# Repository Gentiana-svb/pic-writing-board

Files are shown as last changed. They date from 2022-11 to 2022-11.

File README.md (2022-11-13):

# pic-writing-board

PIC writing board for DIP package with auto guess pin count.

## Core Components

| | |
| --- | --- |
| Analog MUX | TMUX1309BQBR |
| MCU | PIC18F27Q10T-I/ML |
| Comparator | LM2901Q4T |
| SSR | TLP172AM |
| LDO | NJM2845 |
| Power SW | TCP8407 |

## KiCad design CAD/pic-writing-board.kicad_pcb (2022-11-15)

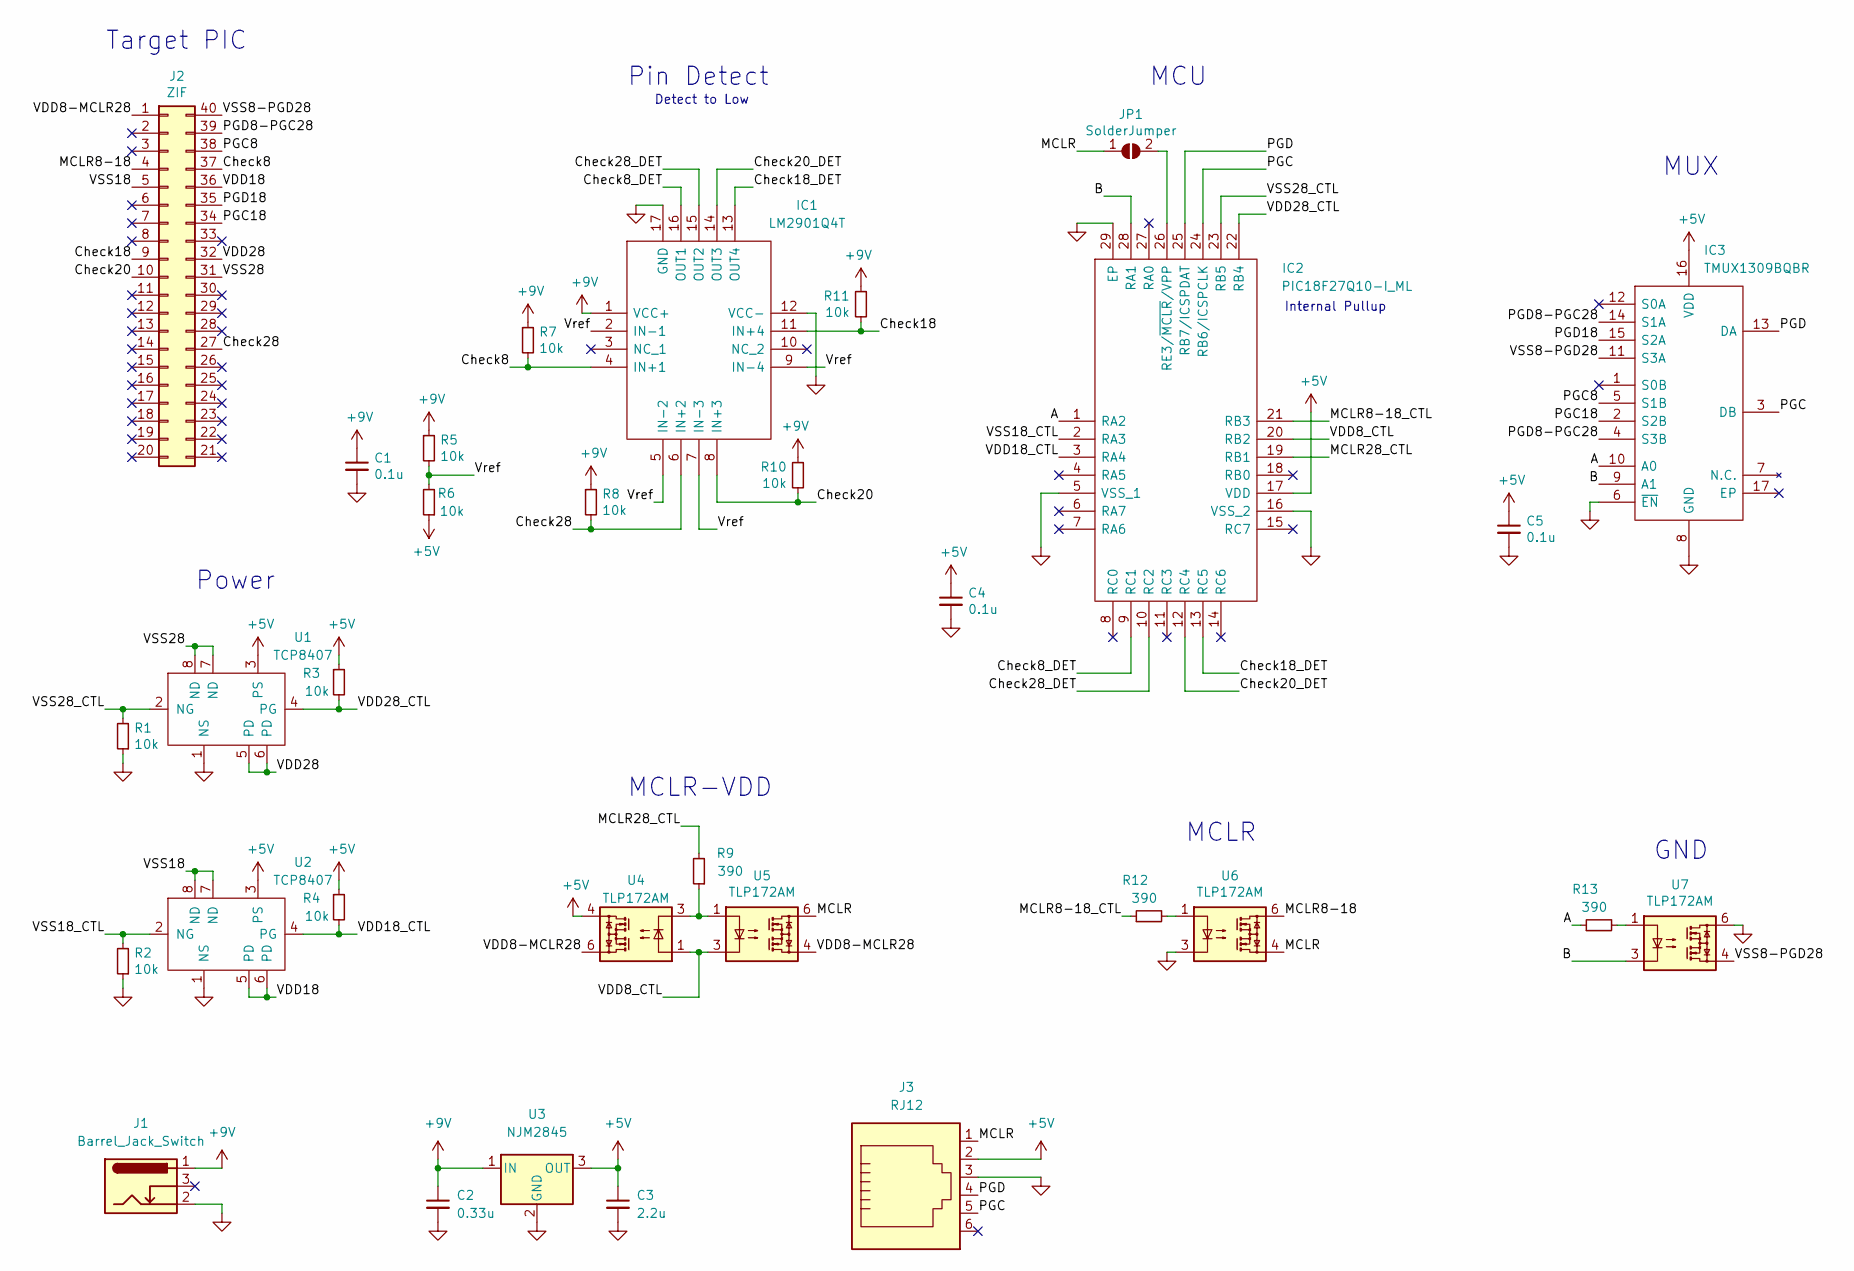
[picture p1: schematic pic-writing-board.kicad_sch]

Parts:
C1, C4, C5: 0.1u; C_0603_1608Metric
C2: 0.33u; C_0603_1608Metric
C3: 2.2u; C_0603_1608Metric
IC1: LM2901Q4T; QFN50P300X300X100-17N; Mouser Part Number 511-LM2901Q4T
IC2: PIC18F27Q10-I_ML; QFN65P600X600X100-29N-D; Mouser Part Number 579-PIC18F27Q10-I/ML
IC3: TMUX1309BQBR; Mouser Part Number 595-TMUX1309BQBR
J1: Barrel_Jack_Switch; BarrelJack_Wuerth_6941xx301002
J2: ZIF
J3: RJ12; 6P6C
JP1: SolderJumper; SolderJumper-2_P1.3mm_Open_RoundedPad1.0x1.5mm
R1, R2, R3, R4, R5, R6, R7, R8, R10, R11: 10k; R_0603_1608Metric
R9, R12, R13: 390; R_0603_1608Metric
U1, U2: TCP8407; SOP-8_3.9x4.9mm_P1.27mm
U3: NJM2845; TO-252-2
U4, U5, U6, U7: TLP172AM; SOIC-4_4.55x3.7mm_P2.54mm

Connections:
+5V: C3.1, C4.1, C5.1, IC2.17 (VDD), IC3.16 (VDD), J3.2, R3.1, R4.1, R6.1, U1.3 (PS), U2.3 (PS), U3.3 (OUT), U4.4
+9V: C1.1, C2.1, IC1.1 (VCC+), J1.1, R5.1, R7.1, R8.1, R10.1, R11.1, U3.1 (IN)
/A: IC2.1 (RA2), IC3.10 (A0), R13.1
/B: IC2.28 (RA1), IC3.9 (A1), U7.3
/Check8: IC1.4 (IN+1), J2.37, R7.2
/Check8_DET: IC1.16 (OUT1), IC2.9 (RC1)
/Check18: IC1.11 (IN+4), J2.9, R11.2
/Check18_DET: IC1.13 (OUT4), IC2.13 (RC5)
/Check20: IC1.8 (IN+3), J2.10, R10.2
/Check20_DET: IC1.14 (OUT3), IC2.12 (RC4)
/Check28: IC1.6 (IN+2), J2.27, R8.2
/Check28_DET: IC1.15 (OUT2), IC2.10 (RC2)
/MCLR: J3.1, JP1.1 (A), U5.6, U6.4
/MCLR8-18: J2.4, U6.6
/MCLR8-18_CTL: IC2.21 (RB3), R12.1
/MCLR28_CTL: IC2.19 (RB1), R9.2
/PGC: IC2.24 (RB6/ICSPCLK), IC3.3 (DB), J3.5
/PGC8: IC3.5 (S1B), J2.38
/PGC18: IC3.2 (S2B), J2.34
/PGD: IC2.25 (RB7/ICSPDAT), IC3.13 (DA), J3.4
/PGD8-PGC28: IC3.4 (S3B), IC3.14 (S1A), J2.39
/PGD18: IC3.15 (S2A), J2.35
/VDD8-MCLR28: J2.1, U4.6, U5.4
/VDD8_CTL: IC2.20 (RB2), U4.1, U5.3
/VDD18: J2.36, U2.5 (PD), U2.6 (PD)
/VDD18_CTL: IC2.3 (RA4), R4.2, U2.4 (PG)
/VDD28: J2.32, U1.5 (PD), U1.6 (PD)
/VDD28_CTL: IC2.22 (RB4), R3.2, U1.4 (PG)
/VSS8-PGD28: IC3.11 (S3A), J2.40, U7.4
/VSS18: J2.5, U2.7 (ND), U2.8 (ND)
/VSS18_CTL: IC2.2 (RA3), R2.2, U2.2 (NG)
/VSS28: J2.31, U1.7 (ND), U1.8 (ND)
/VSS28_CTL: IC2.23 (RB5), R1.2, U1.2 (NG)
/Vref: IC1.2 (IN-1), IC1.5 (IN-2), IC1.7 (IN-3), IC1.9 (IN-4), R5.2, R6.2
GND: C1.2, C2.2, C3.2, C4.2, C5.2, IC1.12 (VCC-), IC1.17 (GND), IC2.5 (VSS_1), IC2.16 (VSS_2), IC2.29 (EP), IC3.6 (~EN), IC3.8 (GND), J1.2, J3.3, R1.1, R2.1, U1.1 (NS), U2.1 (NS), U3.2 (GND), U6.3, U7.6
unnamed: IC2.26 (RE3/~MCLR/VPP), JP1.2 (B)
unnamed: R9.1, U4.3, U5.1
unnamed: R12.2, U6.1
unnamed: R13.2, U7.1

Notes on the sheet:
MCU
MCLR
Internal Pullup
GND
Target PIC
MCLR-VDD
Pin Detect
Power
Detect to Low
MUX

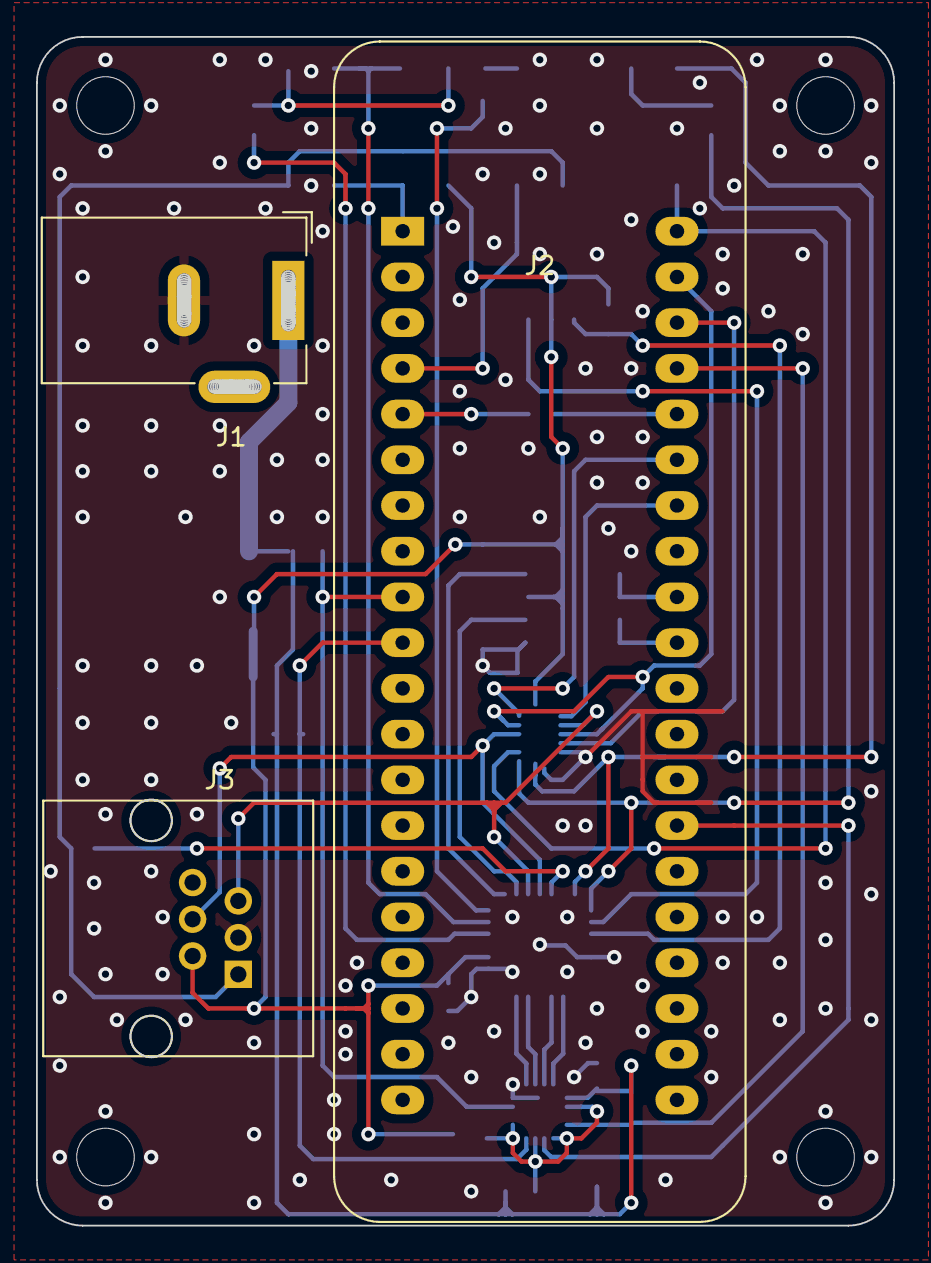
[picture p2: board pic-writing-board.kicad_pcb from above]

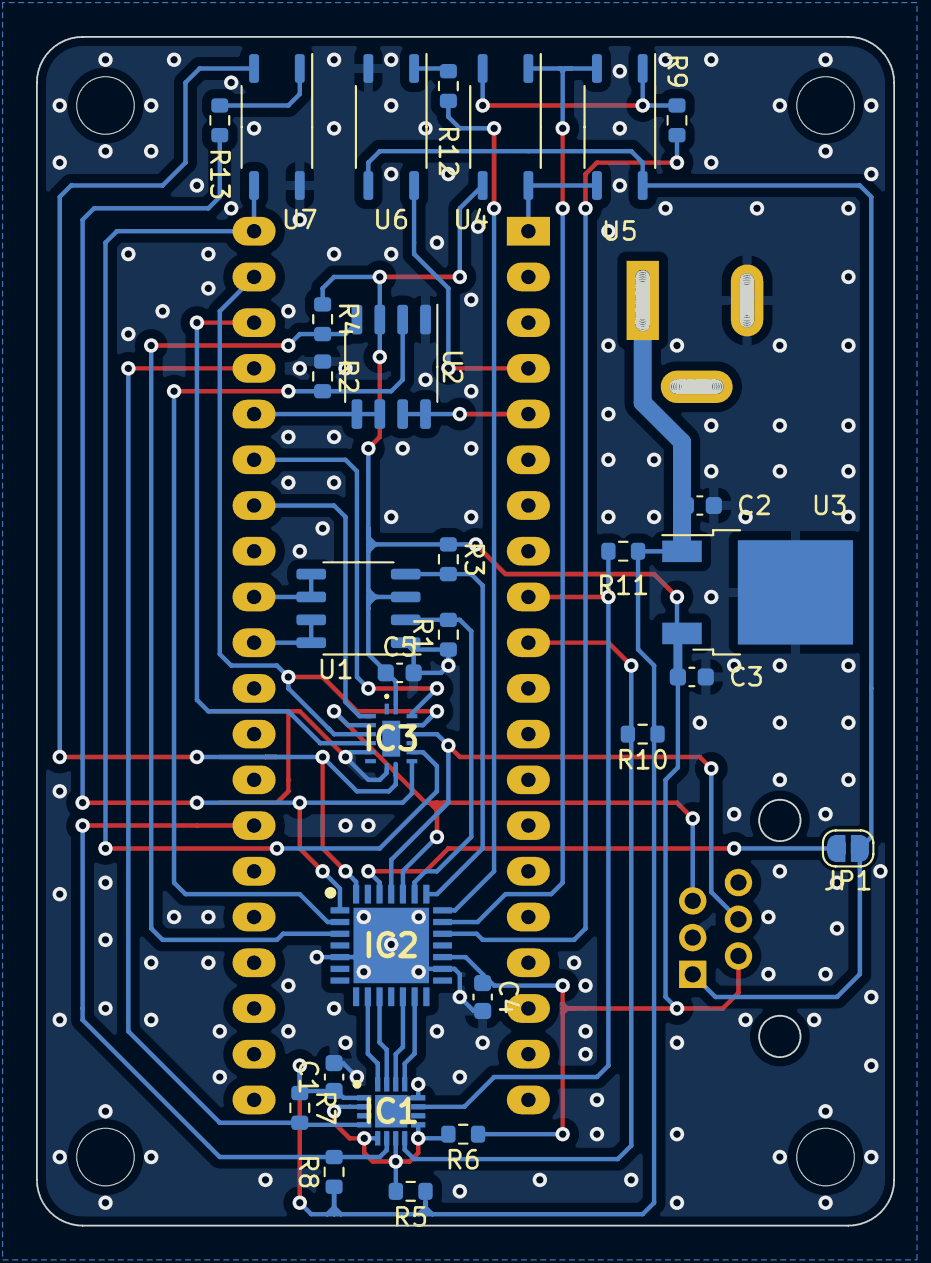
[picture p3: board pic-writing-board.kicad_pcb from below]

Board: 2 copper layers, 47.6 x 66.0 mm, 32 parts (29 on the bottom side), 39 nets.

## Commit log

2022-11-13 add base files
    [pic-writing-board.kicad_pcb, pic-writing-board.kicad_sch]
2022-11-13 add parts
    [pic-writing-board.kicad_sch]
2022-11-14 make sch
    [pic-writing-board.kicad_sch]
2022-11-14 add pcb lib
2022-11-14 import parts
    [pic-writing-board.kicad_pcb, pic-writing-board.kicad_sch]
2022-11-14 adjust port assign
    [pic-writing-board.kicad_sch]
2022-11-14 make pcb
    [pic-writing-board.kicad_pcb, pic-writing-board.kicad_sch]
2022-11-14 adjust sch
    [pic-writing-board.kicad_sch]
2022-11-15 fill pcb
    [pic-writing-board.kicad_pcb]
2022-11-15 add gerber
